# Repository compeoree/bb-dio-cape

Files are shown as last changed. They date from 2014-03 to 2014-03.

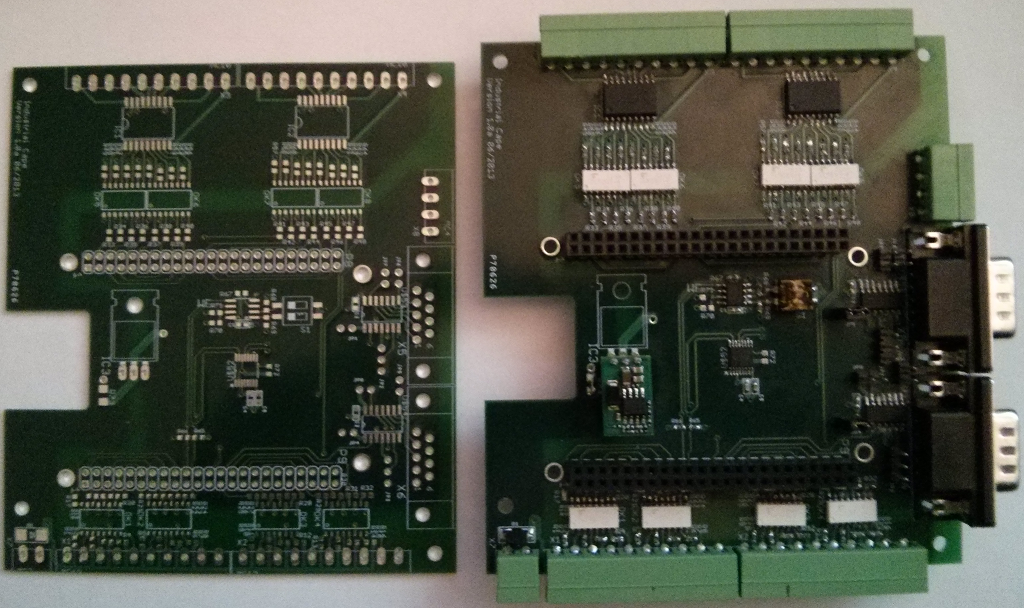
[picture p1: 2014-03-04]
BB_DIO_Cape.png

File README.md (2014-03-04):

bb-dio-cape
===========

Beaglebone Digital I/O Opto Cape

This project contains the Eagle CAD (Version 6.5) files for a four layer circuit board. It maps 15 pins to digital inputs and 16 pins to digital outputs, all of which are optically isolated. It provides pads for a linear (7805) or switching (Murata OKI-78SR-5/1.5-W36H-C) 5v regulator to power the Beaglebone.

Known Issues
============

1) This cape was initially targeted to the Beaglebone White. I attempted to make it compatible with the BeagleBone Black, but I used the wrong pinmux for the eMMC pins.  
Solution:
a) Lose a few inputs/outputs when installed on a BeagleBone Black
b) Remap the affected pins

2) The TLP281 is EOL (End of Life), replace with TLP290

3) The TI DAC7678 requires a 5 volt supply in order to reach the full 5 volt output. This board only provides 3.3v, so the chip can be directly connected to the Beaglebone I2C pins. This limits the DAC to around 3 volts maximum output. A buffer, such as TI PCA9306, would need to be added to raise the DAC7678 to 5v.

4) The MAX3079E will only work in full duplex 4-wire mode. The TX/RX enables are hard wired to always on. They will not work in 2 wire mode, in the current layout.

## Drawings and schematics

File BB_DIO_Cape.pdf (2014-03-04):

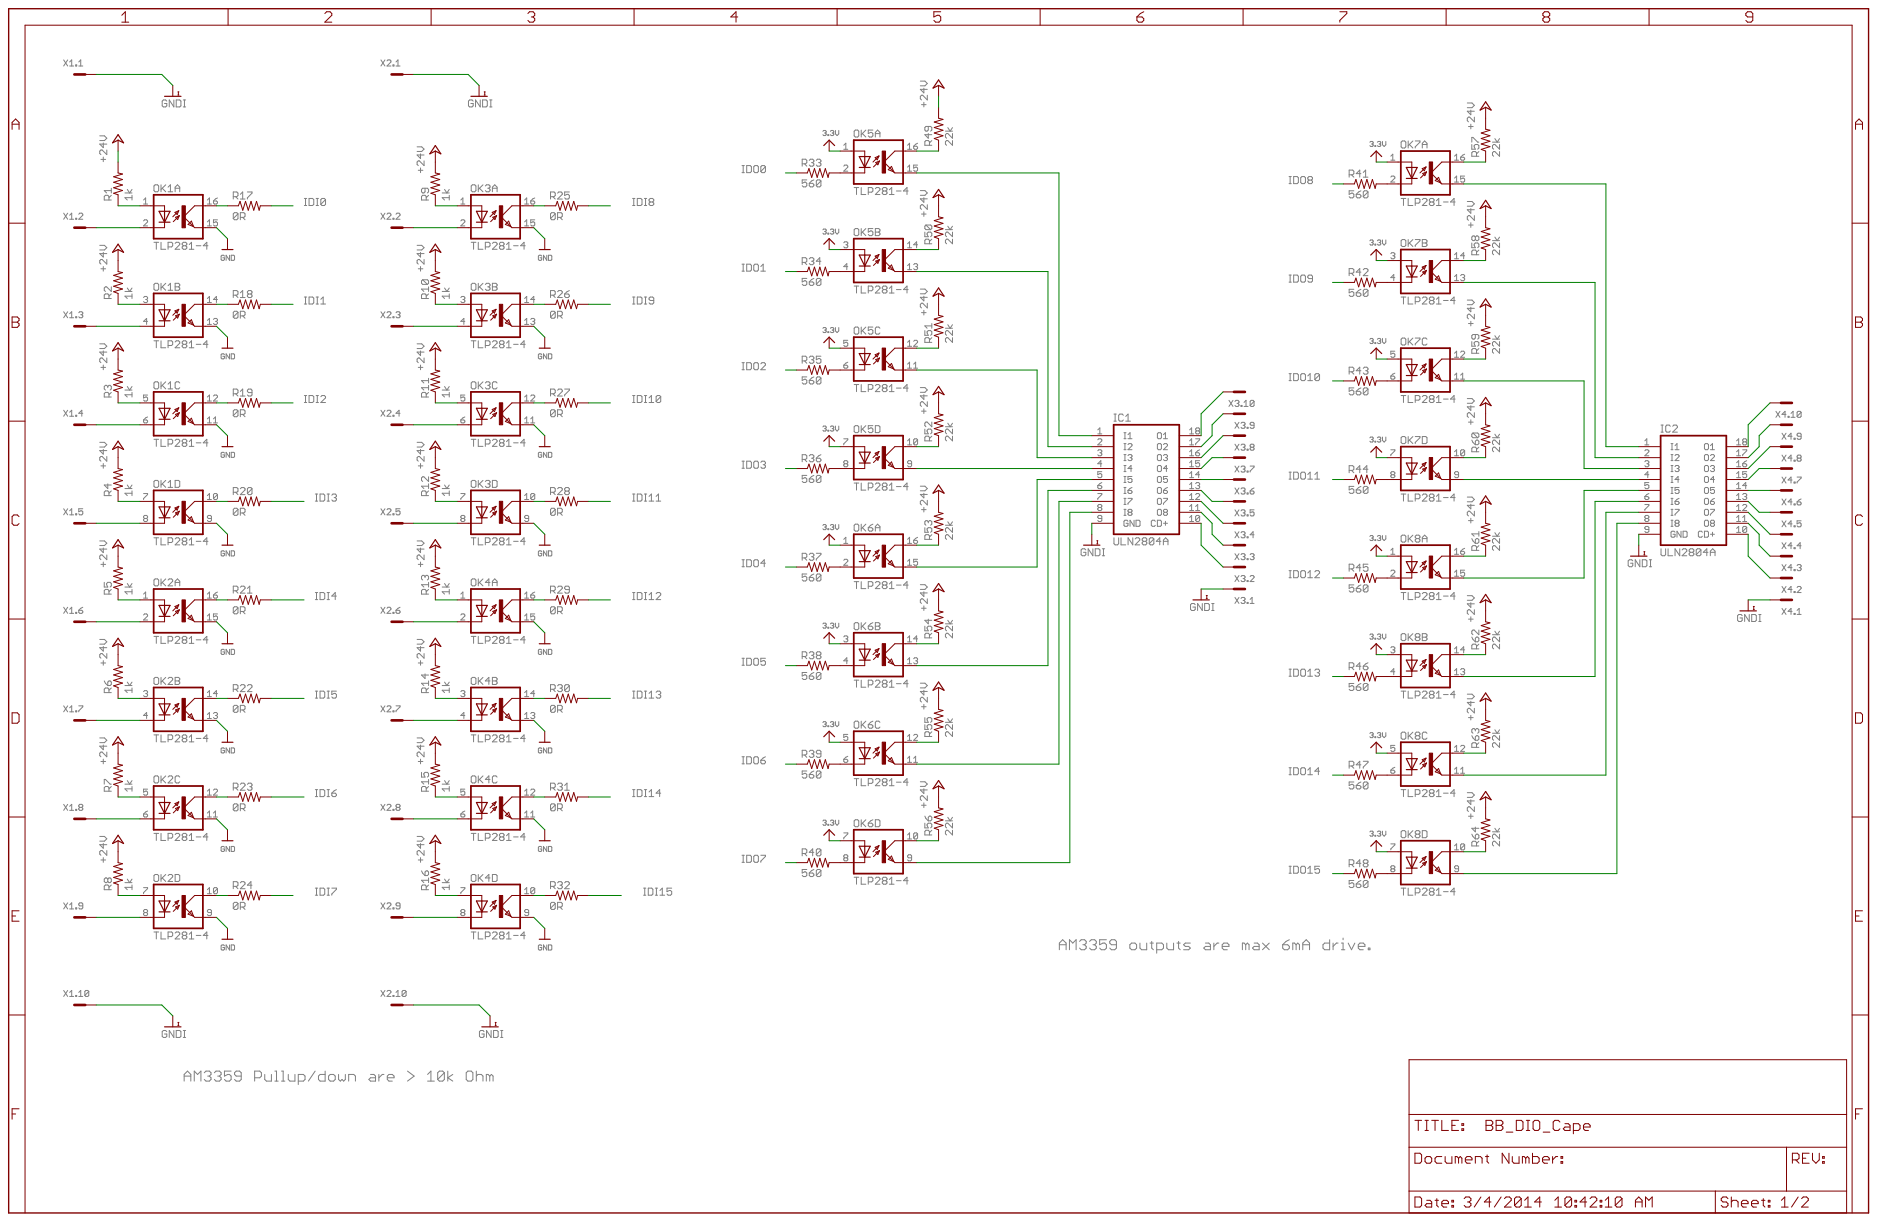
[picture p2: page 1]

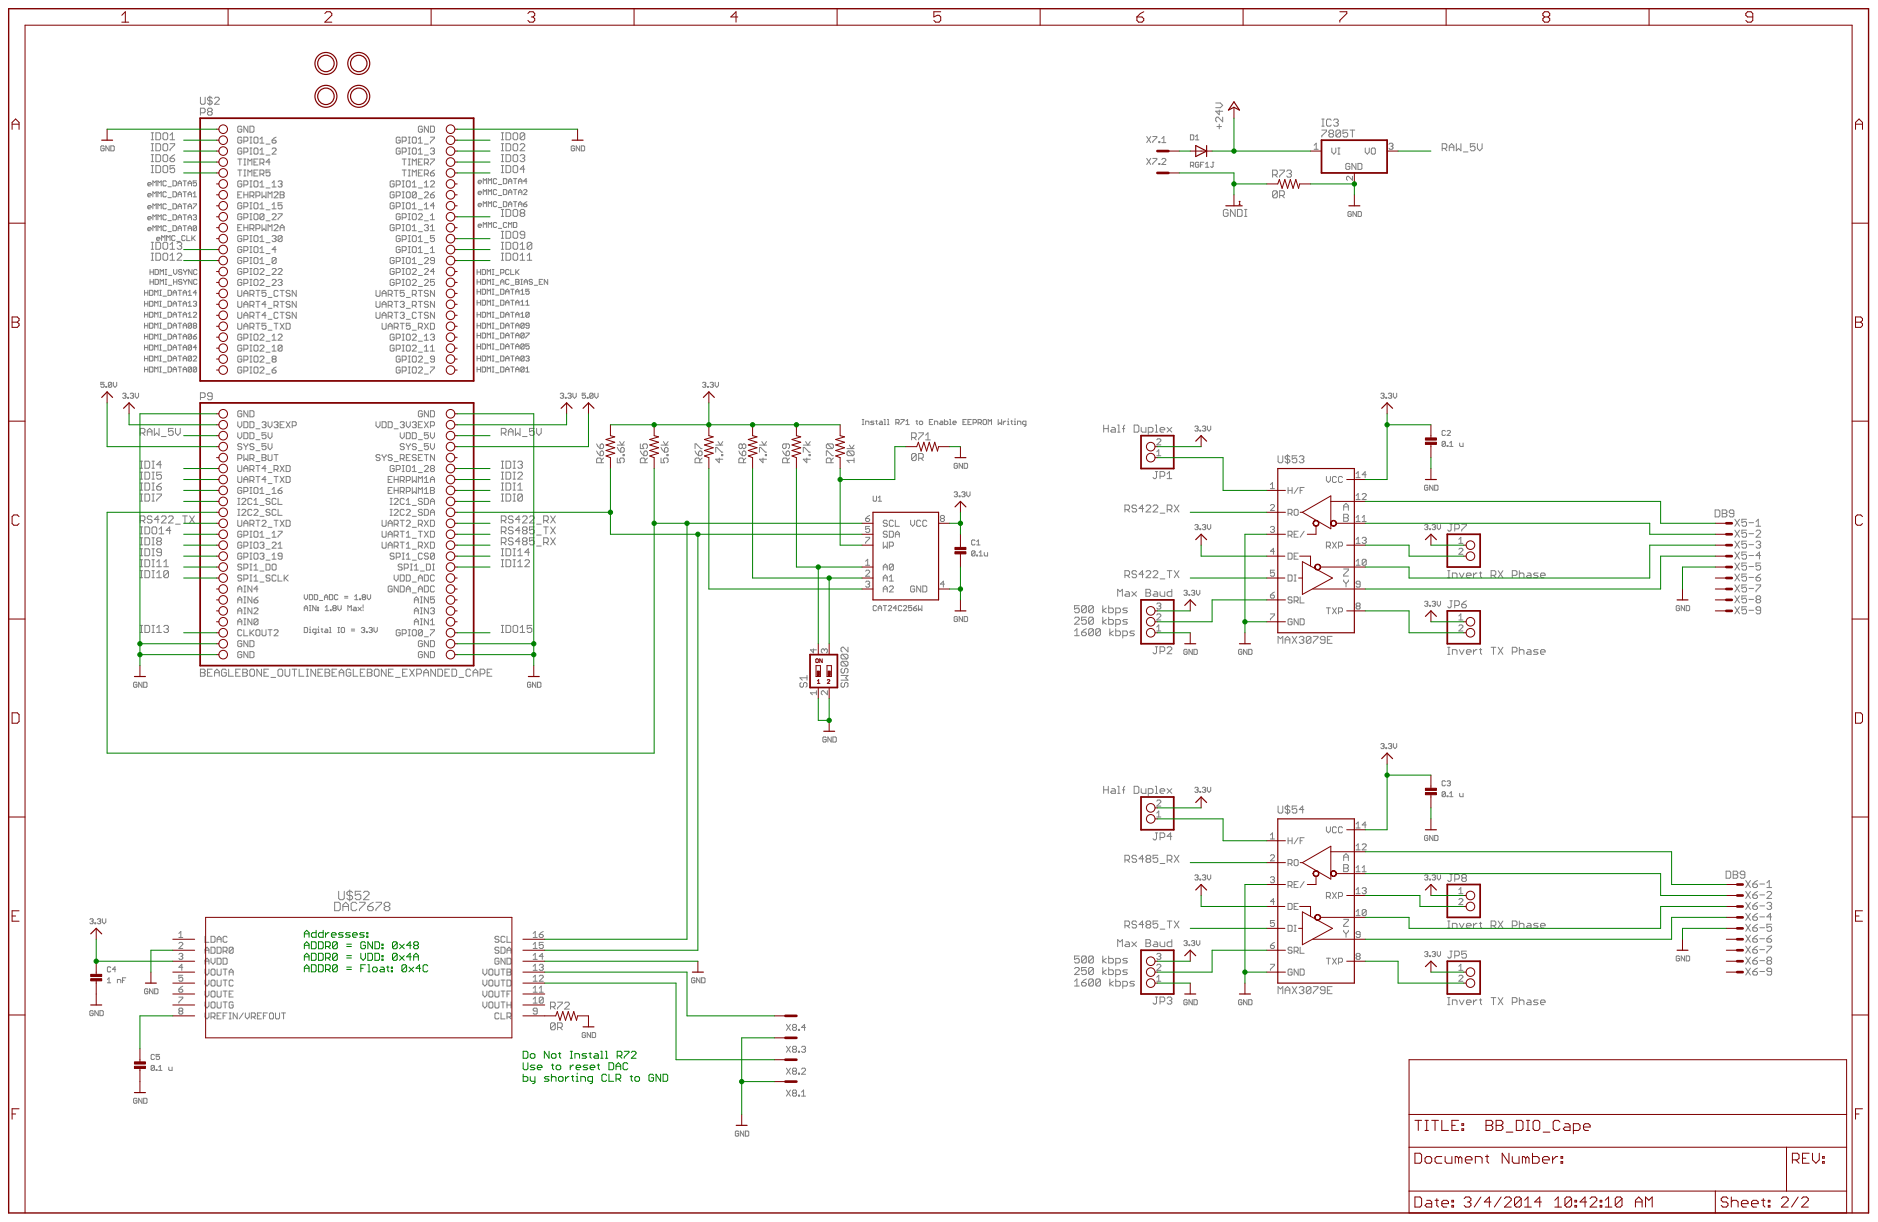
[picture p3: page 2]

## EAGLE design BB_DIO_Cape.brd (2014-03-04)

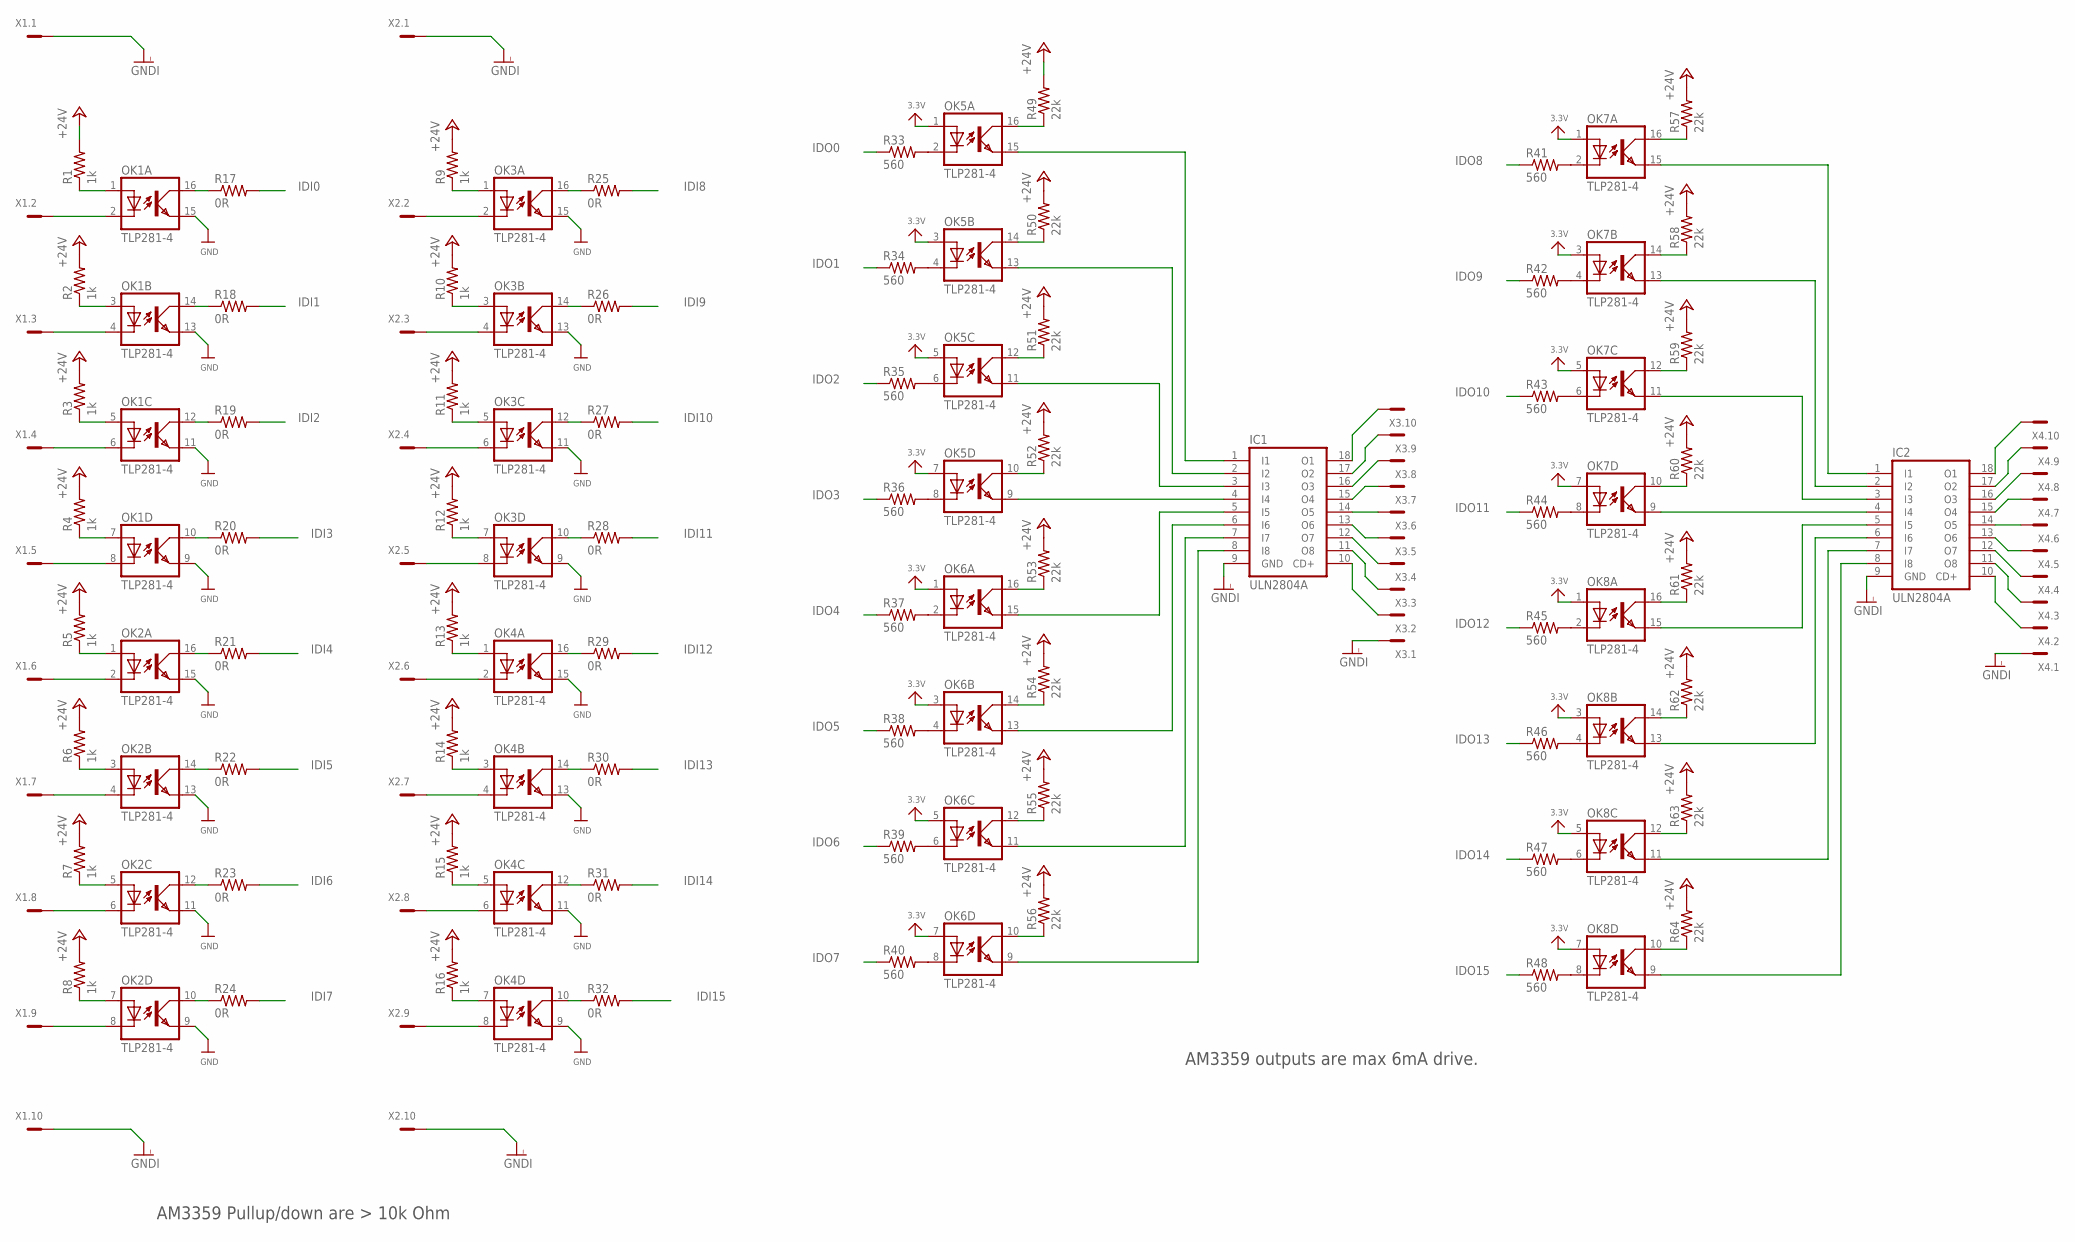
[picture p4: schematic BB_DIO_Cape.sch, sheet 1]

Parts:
IC1, IC2: ULN2804A; SO18W
OK1, OK2, OK3, OK4, OK5, OK6, OK7, OK8: TLP281-4; MINI-FLAT-16
R1, R2, R3, R4, R5, R6, R7, R8, R9, R10, R11, R12, R13, R14, R15, R16: 1k; R0603
R17, R18, R19, R20, R21, R22, R23, R24, R25, R26, R27, R28, R29, R30, R31, R32: 0R; R0603
R33, R34, R35, R36, R37, R38, R39, R40, R41, R42, R43, R44, R45, R46, R47, R48: 560; R0603
R49, R50, R51, R52, R53, R54, R55, R56, R57, R58, R59, R60, R61, R62, R63, R64: 22k; R0603
X1, X2, X3, X4: MC10

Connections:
3.3V: OK5.1 (A), OK5.3 (A), OK5.5 (A), OK5.7 (A), OK6.1 (A), OK6.3 (A), OK6.5 (A), OK6.7 (A), OK7.1 (A), OK7.3 (A), OK7.5 (A), OK7.7 (A), OK8.1 (A), OK8.3 (A), OK8.5 (A), OK8.7 (A); also elsewhere on the board
+24V: R1.2, R2.2, R3.2, R4.2, R5.2, R6.2, R7.2, R8.2, R9.2, R10.2, R11.2, R12.2, R13.2, R14.2, R15.2, R16.2, R49.2, R50.2, R51.2, R52.2, R53.2, R54.2, R55.2, R56.2, R57.2, R58.2, R59.2, R60.2, R61.2, R62.2, R63.2, R64.2; also elsewhere on the board
GND: OK1.9 (EMIT), OK1.11 (EMIT), OK1.13 (EMIT), OK1.15 (EMIT), OK2.9 (EMIT), OK2.11 (EMIT), OK2.13 (EMIT), OK2.15 (EMIT), OK3.9 (EMIT), OK3.11 (EMIT), OK3.13 (EMIT), OK3.15 (EMIT), OK4.9 (EMIT), OK4.11 (EMIT), OK4.13 (EMIT), OK4.15 (EMIT); also elsewhere on the board
GNDI: IC1.9 (GND), IC2.9 (GND), X1.1, X1.10, X2.1, X2.10, X3.1, X4.1; also elsewhere on the board
IDI0: R17.2; also elsewhere on the board
IDI1: R18.2; also elsewhere on the board
IDI2: R19.2; also elsewhere on the board
IDI3: R20.2; also elsewhere on the board
IDI4: R21.2; also elsewhere on the board
IDI5: R22.2; also elsewhere on the board
IDI6: R23.2; also elsewhere on the board
IDI7: R24.2; also elsewhere on the board
IDI8: R25.2; also elsewhere on the board
IDI9: R26.2; also elsewhere on the board
IDI10: R27.2; also elsewhere on the board
IDI11: R28.2; also elsewhere on the board
IDI12: R29.2; also elsewhere on the board
IDI13: R30.2; also elsewhere on the board
IDI14: R31.2; also elsewhere on the board
IDI15: R32.2
IDO0: R33.1; also elsewhere on the board
IDO1: R34.1; also elsewhere on the board
IDO2: R35.1; also elsewhere on the board
IDO3: R36.1; also elsewhere on the board
IDO4: R37.1; also elsewhere on the board
IDO5: R38.1; also elsewhere on the board
IDO6: R39.1; also elsewhere on the board
IDO7: R40.1; also elsewhere on the board
IDO8: R41.1; also elsewhere on the board
IDO9: R42.1; also elsewhere on the board
IDO10: R43.1; also elsewhere on the board
IDO11: R44.1; also elsewhere on the board
IDO12: R45.1; also elsewhere on the board
IDO13: R46.1; also elsewhere on the board
IDO14: R47.1; also elsewhere on the board
IDO15: R48.1; also elsewhere on the board
unnamed: OK4.8 (C), X2.9
unnamed: OK4.7 (A), R16.1
unnamed: OK4.5 (A), R15.1
unnamed: OK4.6 (C), X2.8
unnamed: OK4.4 (C), X2.7
unnamed: OK4.3 (A), R14.1
unnamed: OK4.2 (C), X2.6
unnamed: OK4.1 (A), R13.1
unnamed: OK3.8 (C), X2.5
unnamed: OK3.7 (A), R12.1
unnamed: OK3.6 (C), X2.4
unnamed: OK3.5 (A), R11.1
unnamed: OK3.4 (C), X2.3
unnamed: OK3.3 (A), R10.1
unnamed: OK4.10 (COL), R32.1
unnamed: OK4.12 (COL), R31.1
unnamed: OK4.14 (COL), R30.1
unnamed: OK4.16 (COL), R29.1
unnamed: OK3.10 (COL), R28.1
unnamed: OK3.12 (COL), R27.1
unnamed: OK3.14 (COL), R26.1
unnamed: OK2.10 (COL), R24.1
unnamed: OK2.12 (COL), R23.1
unnamed: OK2.14 (COL), R22.1
unnamed: OK2.16 (COL), R21.1
unnamed: OK1.10 (COL), R20.1
unnamed: OK1.12 (COL), R19.1
unnamed: OK1.14 (COL), R18.1
unnamed: OK1.4 (C), X1.3
unnamed: OK1.3 (A), R2.1
unnamed: OK1.5 (A), R3.1
unnamed: OK1.6 (C), X1.4
unnamed: OK1.7 (A), R4.1
unnamed: OK1.8 (C), X1.5
unnamed: OK2.2 (C), X1.6
unnamed: OK2.1 (A), R5.1
unnamed: OK2.3 (A), R6.1
unnamed: OK2.4 (C), X1.7
unnamed: OK2.5 (A), R7.1
unnamed: OK2.6 (C), X1.8
unnamed: OK2.7 (A), R8.1
unnamed: OK2.8 (C), X1.9
unnamed: OK1.2 (C), X1.2
unnamed: OK1.1 (A), R1.1
unnamed: OK1.16 (COL), R17.1
unnamed: OK3.2 (C), X2.2
unnamed: OK3.1 (A), R9.1
unnamed: OK3.16 (COL), R25.1
unnamed: OK5.2 (C), R33.2
unnamed: OK5.4 (C), R34.2
unnamed: OK5.6 (C), R35.2
unnamed: OK5.8 (C), R36.2
unnamed: OK6.2 (C), R37.2
unnamed: OK6.4 (C), R38.2
unnamed: OK6.6 (C), R39.2
unnamed: OK6.8 (C), R40.2
unnamed: OK7.2 (C), R41.2
unnamed: OK7.4 (C), R42.2
unnamed: OK7.6 (C), R43.2
unnamed: OK7.8 (C), R44.2
unnamed: OK8.2 (C), R45.2
unnamed: OK8.4 (C), R46.2
unnamed: OK8.6 (C), R47.2
unnamed: OK8.8 (C), R48.2
unnamed: OK5.16 (COL), R49.1
unnamed: OK5.14 (COL), R50.1
unnamed: OK5.12 (COL), R51.1
unnamed: OK5.10 (COL), R52.1
unnamed: OK6.16 (COL), R53.1
unnamed: OK6.14 (COL), R54.1
unnamed: OK6.12 (COL), R55.1
unnamed: OK6.10 (COL), R56.1
unnamed: IC1.8 (I8), OK6.9 (EMIT)
unnamed: IC1.7 (I7), OK6.11 (EMIT)
unnamed: IC1.6 (I6), OK6.13 (EMIT)
unnamed: IC1.5 (I5), OK6.15 (EMIT)
unnamed: IC1.4 (I4), OK5.9 (EMIT)
unnamed: IC1.3 (I3), OK5.11 (EMIT)
unnamed: IC1.2 (I2), OK5.13 (EMIT)
unnamed: IC1.1 (I1), OK5.15 (EMIT)
unnamed: OK8.14 (COL), R62.1
unnamed: OK8.12 (COL), R63.1
unnamed: OK8.10 (COL), R64.1
unnamed: IC2.8 (I8), OK8.9 (EMIT)
unnamed: IC2.7 (I7), OK8.11 (EMIT)
unnamed: IC2.6 (I6), OK8.13 (EMIT)
unnamed: IC2.5 (I5), OK8.15 (EMIT)
unnamed: OK8.16 (COL), R61.1
unnamed: OK7.10 (COL), R60.1
unnamed: OK7.12 (COL), R59.1
unnamed: IC2.4 (I4), OK7.9 (EMIT)
unnamed: IC2.3 (I3), OK7.11 (EMIT)
unnamed: IC2.2 (I2), OK7.13 (EMIT)
unnamed: OK7.14 (COL), R58.1
unnamed: OK7.16 (COL), R57.1
unnamed: IC2.1 (I1), OK7.15 (EMIT)
unnamed: IC2.18 (O1), X4.10
unnamed: IC2.10 (CD+), X4.2
unnamed: IC2.11 (O8), X4.3
unnamed: IC2.17 (O2), X4.9
unnamed: IC2.12 (O7), X4.4
unnamed: IC2.13 (O6), X4.5
unnamed: IC2.14 (O5), X4.6
unnamed: IC2.15 (O4), X4.7
unnamed: IC2.16 (O3), X4.8
unnamed: IC1.14 (O5), X3.6
unnamed: IC1.13 (O6), X3.5
unnamed: IC1.12 (O7), X3.4
unnamed: IC1.15 (O4), X3.7
unnamed: IC1.16 (O3), X3.8
unnamed: IC1.17 (O2), X3.9
unnamed: IC1.11 (O8), X3.3
unnamed: IC1.10 (CD+), X3.2
unnamed: IC1.18 (O1), X3.10

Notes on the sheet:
AM3359 Pullup/down are > 10k Ohm
AM3359 outputs are max 6mA drive.

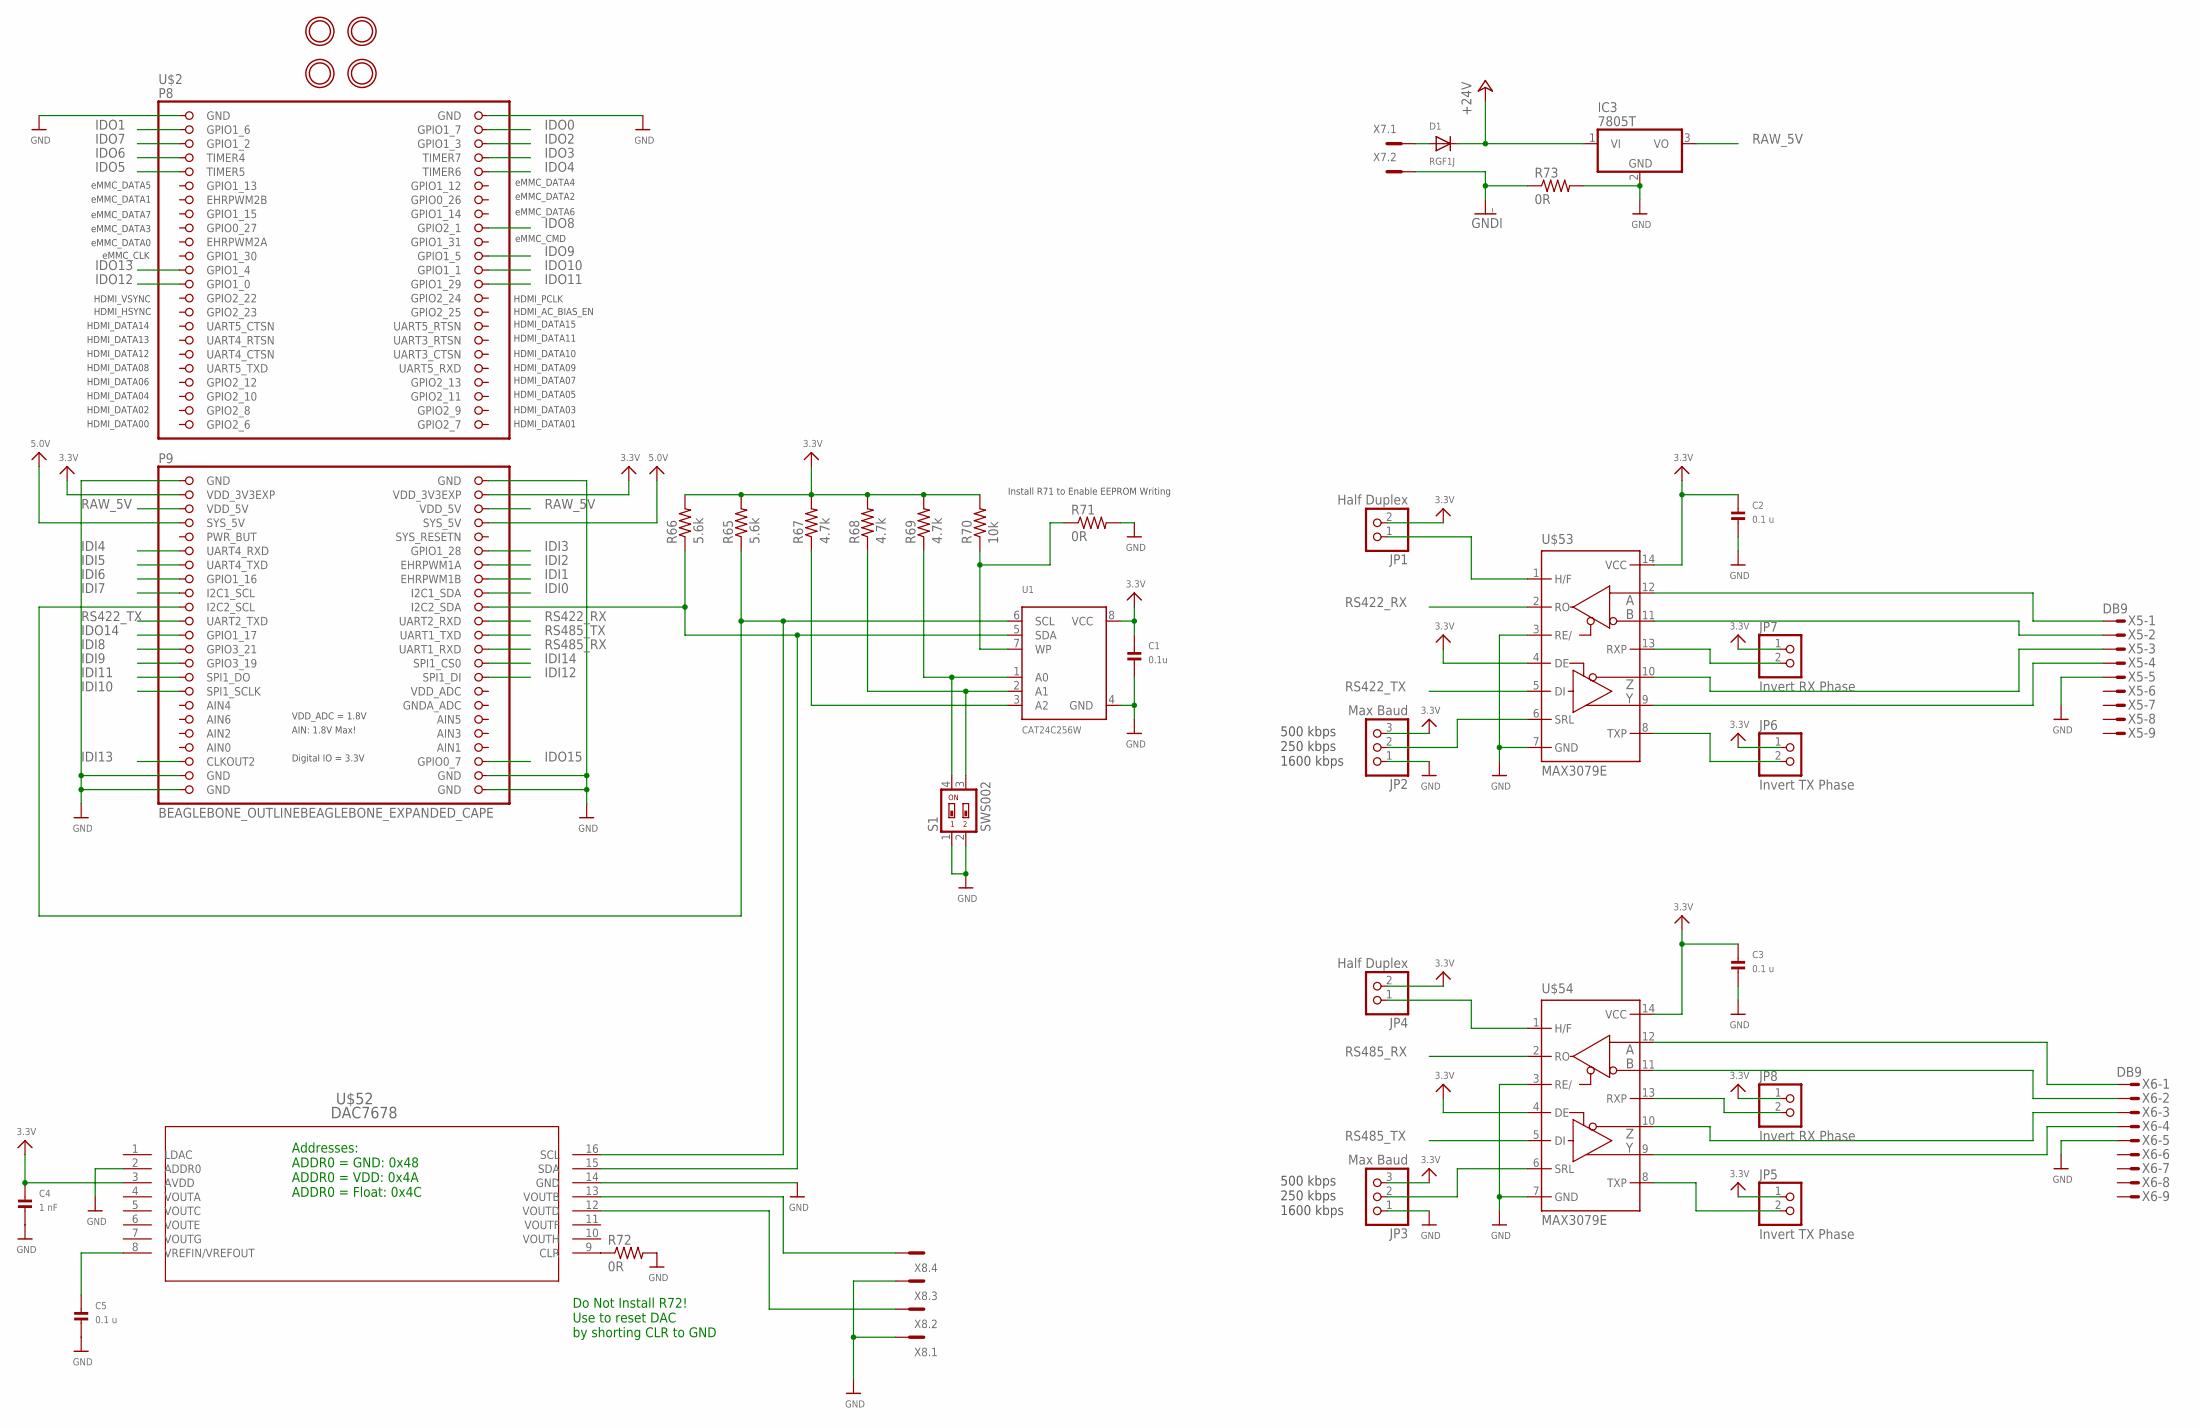
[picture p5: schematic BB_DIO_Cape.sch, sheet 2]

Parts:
C1: 0.1u; _0603
C2, C3, C5: 0.1 u; 0603
C4: 1 nF; 0603
D1: RGF1J; SMADIODE
IC3: 7805T; TO220H
JP1, JP4: Half Duplex; 1X02_ROUND
JP2, JP3: Max Baud; 1X03_ROUND
JP5, JP6: Invert TX Phase; 1X02_ROUND
JP7, JP8: Invert RX Phase; 1X02_ROUND
R65, R66: 5.6k; R0603
R67, R68, R69: 4.7k; R0603
R70: 10k; R0603
R71, R72: 0R; R0603
R73: 0R; M1206
S1: SWS002; SMS-002
U1: CAT24C256W; SOIC8_150MIL
U$2: BEAGLEBONE_OUTLINEBEAGLEBONE_EXPANDED_CAPE; BEAGLEBONE_SHIELD
U$22, U$23, U$71, U$72: MOUNTINGHOLE3.0THIN; MOUNTINGHOLE_3.0_PLATEDTHIN
U$52: DAC7678; PW16
U$53, U$54: MAX3079E; SO14
X5, X6: DB9; 182-009-MALE
X7: MC2
X8: MC4

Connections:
3.3V: C1.1, C2.1, C3.1, C4.1, JP1.2, JP2.3, JP3.3, JP4.2, JP5.1, JP6.1, JP7.1, JP8.1, R65.2, R66.2, R67.2, R68.2, R69.2, R70.2, U1.8 (VCC), U$2.49 (VDD_3V3EXP), U$2.50 (VDD_3V3EXP), U$52.3 (AVDD), U$53.4 (DE), U$53.14 (VCC), U$54.4 (DE), U$54.14 (VCC); also elsewhere on the board
5.0V: U$2.53 (SYS_5V), U$2.54 (SYS_5V)
+24V: D1.C, IC3.1 (VI); also elsewhere on the board
GND: C1.2, C2.2, C3.2, C4.2, C5.2, IC3.2 (GND), JP2.1, JP3.1, R71.2, R72.2, R73.2, S1.1, S1.2, U1.4 (GND), U$2.1 (GND), U$2.2 (GND), U$2.47 (GND), U$2.48 (GND), U$2.89 (GND), U$2.90 (GND), U$2.91 (GND), U$2.92 (GND), U$52.2 (ADDR0), U$52.14 (GND), U$53.3 (RE/), U$53.7 (GND), U$54.3 (RE/), U$54.7 (GND), X5.5, X6.5, X8.1, X8.3; also elsewhere on the board
GNDA_ADC: U$2.80 (GNDA_ADC)
GNDI: R73.1, X7.2; also elsewhere on the board
IDI0: U$2.64 (I2C1_SDA); also elsewhere on the board
IDI1: U$2.62 (EHRPWM1B); also elsewhere on the board
IDI2: U$2.60 (EHRPWM1A); also elsewhere on the board
IDI3: U$2.58 (GPIO1_28); also elsewhere on the board
IDI4: U$2.57 (UART4_RXD); also elsewhere on the board
IDI5: U$2.59 (UART4_TXD); also elsewhere on the board
IDI6: U$2.61 (GPIO1_16); also elsewhere on the board
IDI7: U$2.63 (I2C1_SCL); also elsewhere on the board
IDI8: U$2.71 (GPIO3_21); also elsewhere on the board
IDI9: U$2.73 (GPIO3_19); also elsewhere on the board
IDI10: U$2.77 (SPI1_SCLK); also elsewhere on the board
IDI11: U$2.75 (SPI1_DO); also elsewhere on the board
IDI12: U$2.76 (SPI1_DI); also elsewhere on the board
IDI13: U$2.87 (CLKOUT2); also elsewhere on the board
IDI14: U$2.74 (SPI1_CS0); also elsewhere on the board
IDO0: U$2.4 (GPIO1_7); also elsewhere on the board
IDO1: U$2.3 (GPIO1_6); also elsewhere on the board
IDO2: U$2.6 (GPIO1_3); also elsewhere on the board
IDO3: U$2.8 (TIMER7); also elsewhere on the board
IDO4: U$2.10 (TIMER6); also elsewhere on the board
IDO5: U$2.9 (TIMER5); also elsewhere on the board
IDO6: U$2.7 (TIMER4); also elsewhere on the board
IDO7: U$2.5 (GPIO1_2); also elsewhere on the board
IDO8: U$2.18 (GPIO2_1); also elsewhere on the board
IDO9: U$2.22 (GPIO1_5); also elsewhere on the board
IDO10: U$2.24 (GPIO1_1); also elsewhere on the board
IDO11: U$2.26 (GPIO1_29); also elsewhere on the board
IDO12: U$2.25 (GPIO1_0); also elsewhere on the board
IDO13: U$2.23 (GPIO1_4); also elsewhere on the board
IDO14: U$2.69 (GPIO1_17); also elsewhere on the board
IDO15: U$2.88 (GPIO0_7); also elsewhere on the board
unnamed: D1.A, X7.1
unnamed: C5.1, U$52.8 (VREFIN/VREFOUT)
unnamed: R72.1, U$52.9 (CLR)
unnamed: JP3.2, U$54.6 (SRL)
unnamed: R69.1, S1.4, U1.1 (A0)
unnamed: R70.1, R71.1, U1.7 (WP)
unnamed: JP2.2, U$53.6 (SRL)
unnamed: JP7.2, U$53.13 (RXP)
unnamed: JP6.2, U$53.8 (TXP)
unnamed: JP5.2, U$54.8 (TXP)
unnamed: JP4.1, U$54.1 (H/F)
unnamed: JP1.1, U$53.1 (H/F)
unnamed: JP8.2, U$54.13 (RXP)
unnamed: U$52.13 (VOUTB), X8.4
unnamed: U$52.12 (VOUTD), X8.2
unnamed: U$54.9 (Y), X6.4
unnamed: U$53.10 (Z), X5.3
unnamed: U$53.9 (Y), X5.4
unnamed: U$53.12 (A), X5.1
unnamed: U$53.11 (B), X5.2
unnamed: U$54.11 (B), X6.2
unnamed: U$54.12 (A), X6.1
unnamed: U$54.10 (Z), X6.3
unnamed: R68.1, S1.3, U1.2 (A1)
unnamed: R67.1, U1.3 (A2)
RAW_5V: IC3.3 (VO), U$2.51 (VDD_5V), U$2.52 (VDD_5V)
RS422_RX: U$2.68 (UART2_RXD), U$53.2 (RO)
RS422_TX: U$2.67 (UART2_TXD), U$53.5 (DI)
RS485_RX: U$2.72 (UART1_RXD), U$54.2 (RO)
RS485_TX: U$2.70 (UART1_TXD), U$54.5 (DI)
SCL: R65.1, U1.6 (SCL), U$2.65 (I2C2_SCL), U$52.16 (SCL)
SDA: R66.1, U1.5 (SDA), U$2.66 (I2C2_SDA), U$52.15 (SDA)
VDD_ADC: U$2.78 (VDD_ADC)

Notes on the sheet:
HDMI_VSYNC
HDMI_PCLK
HDMI_HSYNC
HDMI_AC_BIAS_EN
HDMI_DATA14
HDMI_DATA15
HDMI_DATA13
HDMI_DATA11
HDMI_DATA12
HDMI_DATA10
HDMI_DATA08
HDMI_DATA09
HDMI_DATA06
HDMI_DATA07
HDMI_DATA04
HDMI_DATA05
HDMI_DATA02
HDMI_DATA03
HDMI_DATA00
HDMI_DATA01
eMMC_DATA5
eMMC_DATA4
eMMC_DATA1
eMMC_DATA2
eMMC_DATA7
eMMC_DATA6
eMMC_DATA3
eMMC_DATA0
eMMC_CMD
eMMC_CLK
Install R71 to Enable EEPROM Writing
Addresses: ADDR0 = GND: 0x48 ADDR0 = VDD: 0x4A ADDR0 = Float: 0x4C
Do Not Install R72! Use to reset DAC by shorting CLR to GND
500 kbps 250 kbps 1600 kbps

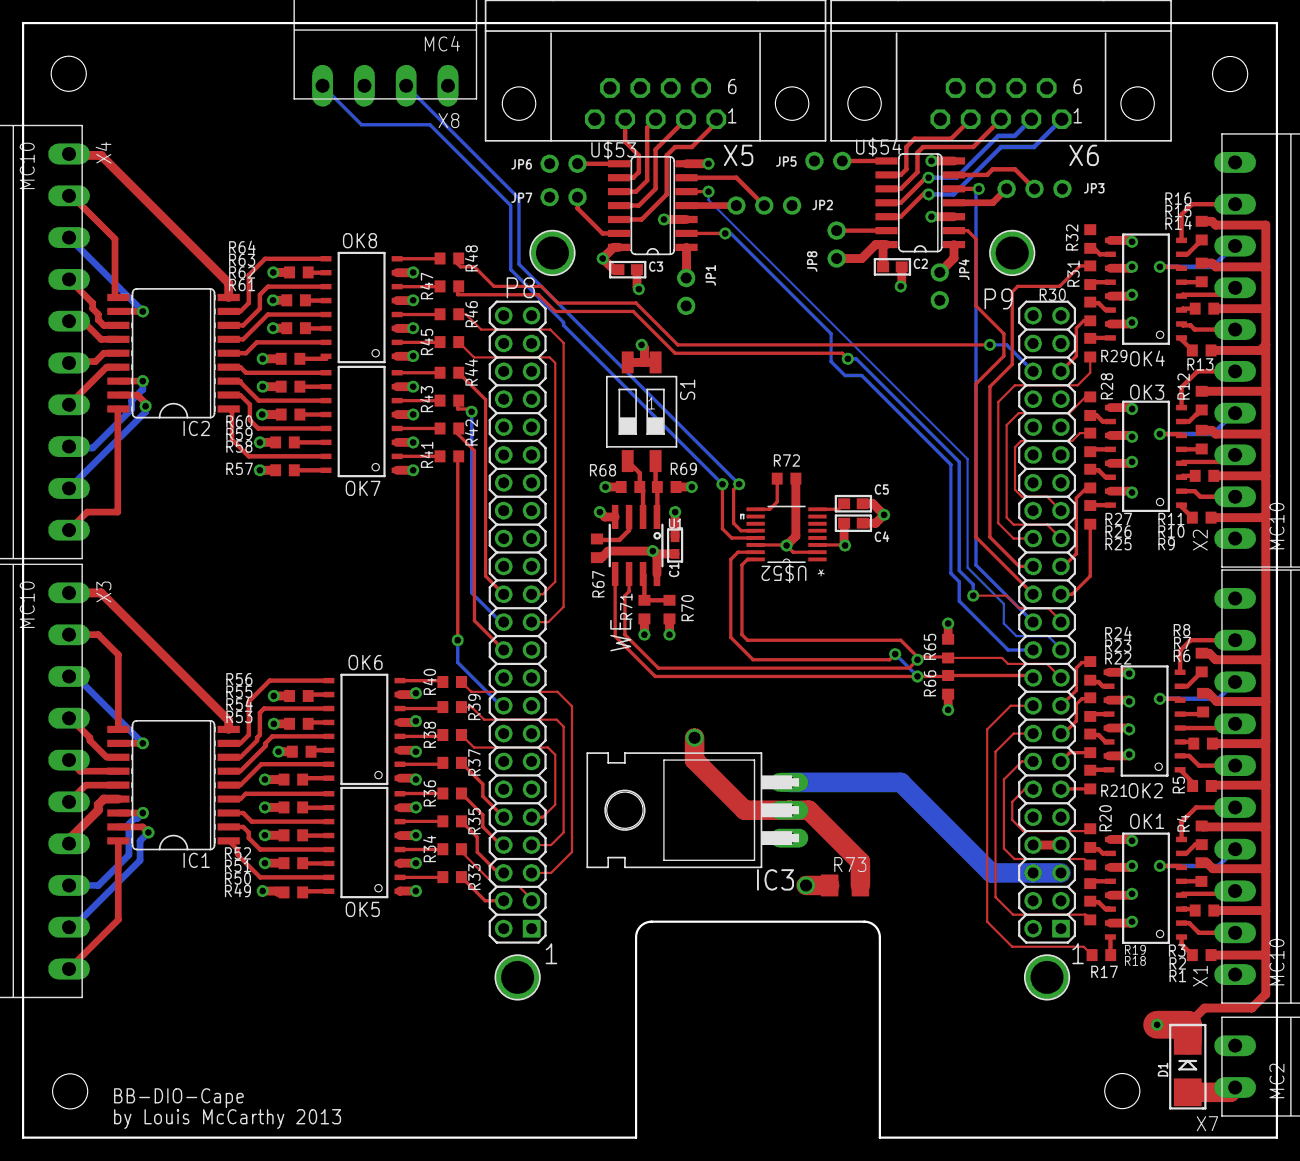
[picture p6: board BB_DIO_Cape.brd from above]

Board: 4 copper layers, 114.3 x 101.6 mm, 116 parts (0 on the bottom side), 182 nets.

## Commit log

2014-03-04 Added project files
    [BB_DIO_Cape.brd, BB_DIO_Cape.sch]
2014-03-17 Added device tree overlay source file
